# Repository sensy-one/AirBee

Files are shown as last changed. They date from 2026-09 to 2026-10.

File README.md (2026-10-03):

# SENSY-ONE AirBee

Ultra-low-power air quality sensor for **Home Assistant** and **Homey Pro**,
with selectable Zigbee or Bluetooth Low Energy connectivity.

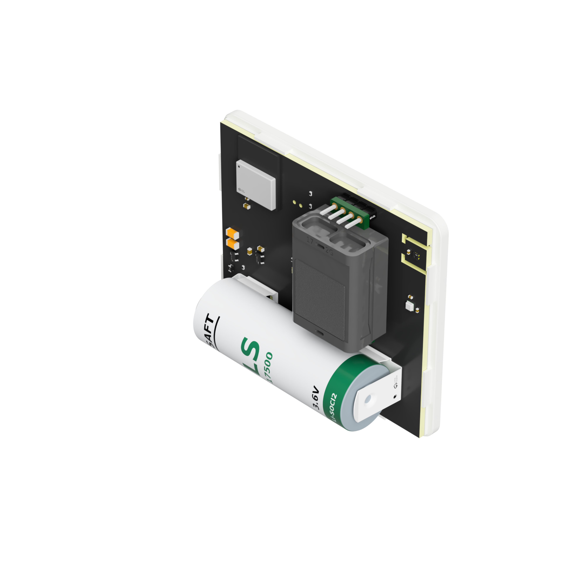
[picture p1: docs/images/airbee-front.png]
Sensy-One AirBee


AirBee measures CO₂, temperature, relative humidity and atmospheric pressure
every five minutes. It uses the pressure reading to compensate the CO₂ sensor
and keeps automatic calibration active while saving power between measurements.

### Smart Home Compatibility

| Platform | Connection | Integration |
|---|---|---|
| Home Assistant | Zigbee | [Zigbee2MQTT](#zigbee2mqtt) or [ZHA](#zha) |
| Home Assistant | Bluetooth LE | [BTHome](#home-assistant-with-bluetooth-le-bthome) |
| Homey Pro | Zigbee or Bluetooth LE | [SENSY-ONE app in the Homey App Store](https://homey.app/en-nl/app/com.sensy-one.airbee/SENSY-ONE/test/) |

All options provide CO₂, temperature, humidity and pressure measurements.
AirBee uses one wireless mode at a time and can join one Zigbee network at a time.

Key features:

- Selectable Zigbee or Bluetooth Low Energy connectivity
- Home Assistant support through Zigbee2MQTT, ZHA or BTHome
- Homey Pro support through the SENSY-ONE app, with Zigbee and Bluetooth LE
- Five-minute CO₂, temperature, humidity and pressure measurements
- Pressure compensation for CO₂ measurements
- Automatic CO₂ baseline calibration
- Manual outdoor-air calibration when needed
- Signed Bluetooth firmware updates without programming hardware

## Getting Started

1. Insert a **SAFT LS17500 3.6 V battery**, following the + and − markings.
   AirBee starts automatically. Leave the button released while inserting the
   battery; holding it during startup starts CO₂ calibration.
2. Check the startup LED: **four red flashes mean Zigbee**, and **four blue
   flashes mean Bluetooth LE**. A new device starts in Zigbee mode.
3. Use the button controls below to select a wireless mode, then follow the
   connection steps for your platform below.

### Button Controls

With AirBee powered on, hold the button until the desired indication, then
release it to confirm. Keep holding past the earlier indications to reach
firmware update or reset.

| Button action | Function | LED indication |
|---|---|---|
| Short press | No action | None |
| Hold for **5 seconds**, then release | Switch between Zigbee and Bluetooth LE | Four red flashes for Zigbee or four blue flashes for Bluetooth LE |
| Hold for **12 seconds**, then release | Start Bluetooth firmware update mode | Green flashes; continuous green blinking after release |
| Hold for **20 seconds**, then release | Clear Zigbee pairing and join a network | Fast red blinking; AirBee restarts in Zigbee mode |
| Hold while inserting the battery | Start [outdoor-air calibration](#co₂-calibration) immediately | Alternating red and blue; solid green on success or solid red on failure |

### Home Assistant with Zigbee

Use either Zigbee2MQTT or ZHA with a compatible Zigbee coordinator. Start pairing
in your chosen integration:

#### Zigbee2MQTT

Open Zigbee2MQTT and enable **Permit join**. To make measurements appear in
Home Assistant, enable Zigbee2MQTT's **Home Assistant discovery** and set up the
[MQTT integration](https://www.home-assistant.io/integrations/mqtt/) in Home
Assistant using the same MQTT broker. See the
[Zigbee2MQTT setup guide](https://www.zigbee2mqtt.io/guide/usage/integrations/home_assistant.html).

#### ZHA

In Home Assistant, open **Settings → Connectivity → Zigbee → Add device**.
If ZHA is not set up yet, follow the
[ZHA setup guide](https://www.home-assistant.io/integrations/zha/).

#### Pair AirBee

1. Enable joining as described above for your integration.
2. Start AirBee in Zigbee mode (**four red flashes**). If it is already powered
   on, remove the battery for at least three seconds and reinsert it with the
   button released.
3. AirBee searches for a network automatically. Wait for the interview to finish,
   then name the device and assign it to a room in Home Assistant.

If AirBee was previously paired, follow [Reset & Re-pair](#reset--re-pair) below.
Allow up to five minutes for measurements to appear.

### Reset & Re-pair

1. Enable pairing on your Zigbee coordinator.
2. With AirBee powered on, hold the button for **20 seconds**. Keep holding
   through the mode flashes and green firmware-update indication.
3. Release when the LED starts **blinking red quickly**.
4. AirBee clears its saved Zigbee network settings, restarts in Zigbee mode and
   automatically searches for a network.

This works from either wireless mode and preserves CO₂ calibration. Removing
the battery or switching modes does not clear the Zigbee pairing.

### Home Assistant with Bluetooth LE (BTHome)

1. Make sure Home Assistant's Bluetooth integration is set up with a working
   Bluetooth adapter or Bluetooth proxy.
2. Select Bluetooth mode (**four blue flashes**) using the button controls above.
3. In Home Assistant, open **Settings → Devices & services** and add the
   discovered **BTHome** device. No Bluetooth pairing or pairing reset is needed.

[BTHome](https://www.home-assistant.io/integrations/bthome/) is built into Home
Assistant; no custom integration is required.

Place AirBee where room air can reach the sensor and allow up to five minutes
for measurements to appear. The LED stays off during normal operation to save
power. A short button press does not trigger a measurement.

### Connect with Homey Pro

1. Open [SENSY-ONE in the Homey App Store](https://homey.app/en-nl/app/com.sensy-one.airbee/SENSY-ONE/test/)
   and select **Install App**. Sign in and choose your Homey Pro.
2. In Homey, go to **Devices, Add device, SENSY-ONE** and choose **AirBee Zigbee**
   or **AirBee BLE**, matching your sensor's wireless mode.

The app is under review by Homey, but you can already install and use it through
the test link above. The App Store warning means the review is still pending.

## Measurements and Accuracy

| Measurement | Sensor | Sensor range | Typical accuracy |
|---|---|---:|---:|
| CO₂ | [Senseair Sunrise](https://senseair.com/product/sunrise/) | 0–10,000 ppm | ±30 ppm + 3% of reading |
| Temperature | [Sensirion SHT45](https://sensirion.com/products/catalog/SHT45) | −40 to 125 °C | ±0.1 °C |
| Relative humidity | [Sensirion SHT45](https://sensirion.com/products/catalog/SHT45) | 0–100 %RH | ±1.0 %RH |
| Pressure | [Bosch BMP581](https://www.bosch-sensortec.com/products/environmental-sensors/pressure-sensors/bmp581/) | 300–1,250 hPa | ±30 Pa absolute at 300–1,100 hPa and −5 to 65 °C; ±6 Pa relative at 700–1,100 hPa and 15 to 55 °C |

Published resolution:

- CO₂: 1 ppm
- Temperature: 0.01 °C
- Relative humidity: 0.01 %RH
- Pressure: 1 hPa

Temperature is transmitted in degrees Celsius. A smart-home frontend can display
the same measurement in Fahrenheit.

## Power and Battery Life

AirBee is designed for the **SAFT LS17500**, a 3.6 V lithium-thionyl-chloride
battery with 3,600 mAh nominal capacity. The estimates below use the average
current measured over **five hours** in each wireless mode, with one measurement
cycle every five minutes.

| Wireless mode | Measured average | No self-discharge | 1% self-discharge per year |
|---|---:|---:|---:|
| Zigbee | **14.74 µA** | **27.88 years** | **≈24.58 years** |
| Bluetooth LE | **12.44 µA** | **33.04 years** | **≈28.53 years** |

The expected battery life is **at least 10 years** with one measurement cycle
every five minutes.

### Performance Test

- [Zigbee - 14.74 µA average over 5 hours](docs/images/airbee-zigbee-power-test-5h.png)
- [Bluetooth LE - 12.44 µA average over 5 hours](docs/images/airbee-ble-power-test-5h.png)

## Wireless Connectivity

### Zigbee

AirBee operates as a sleepy end device and publishes standard Zigbee Cluster
Library measurements:

| Cluster | ID |
|---|---:|
| Basic | `0x0000` |
| Identify | `0x0003` |
| Temperature Measurement | `0x0402` |
| Pressure Measurement | `0x0403` |
| Relative Humidity Measurement | `0x0405` |
| Carbon Dioxide Concentration Measurement | `0x040D` |

- Model: `AirBee`
- Manufacturer: `SENSY-ONE`

No manufacturer-specific measurement payload or custom Zigbee stack is used.

### Bluetooth Low Energy

Bluetooth mode works with Home Assistant through its built-in
[BTHome integration](https://www.home-assistant.io/integrations/bthome/).
No custom integration or pairing is needed.

AirBee sends CO₂, temperature, humidity and pressure using
[BTHome v2](https://bthome.io/). Allow up to five minutes for the next broadcast.

## CO₂ Calibration

AirBee uses automatic CO₂ baseline calibration with a fresh-air reference of
430 ppm. Calibration is retained between measurements, even while the CO₂ sensor
is powered down.

For installation or service, AirBee also provides a protected outdoor-air
calibration:

1. Place AirBee outdoors, away from people, open doors, combustion sources and
   traffic exhaust.
2. Remove the battery for at least three seconds.
3. Hold the button while inserting the battery. Calibration starts immediately;
   release the button when the LED begins alternating red and blue.
4. Leave AirBee undisturbed outdoors while the Sunrise takes repeated
   stabilization measurements and calibrates, which takes approximately ten
   minutes.
5. A solid green LED confirms success; a solid red LED indicates that
   calibration failed. The result remains visible until power is removed.
6. Remove the battery for at least three seconds, then insert it again without
   pressing the button. AirBee starts in its previously selected wireless mode.

Only use this procedure when AirBee is exposed to clean, stable outdoor air. Do
not calibrate indoors, near a person breathing onto the sensor, close to a road,
or near combustion equipment.

## Firmware Updates

Update AirBee wirelessly over Bluetooth Low Energy with Silicon Labs
Simplicity Connect.

1. Download [AirBee-update.gbl](firmware/v1.0.1/AirBee-update.gbl)
   using **Download raw file** on the file page.
2. Install Silicon Labs Simplicity Connect for
   [Android](https://play.google.com/store/apps/details?id=com.siliconlabs.bledemo)
   or [iOS](https://apps.apple.com/us/app/simplicity-connect/id1030932759).
3. Hold the AirBee button for 12 seconds. Continue holding after the first mode
   indication and release the button after the LED flashes green, before
   reaching the 20-second reset indication.
4. Open **Scan** in Simplicity Connect and scan for nearby devices.
5. Connect to **AirBee DFU**.
6. In the connected device view, tap **OTA Firmware** in the upper-right corner
   to open the update menu.
7. Set **Type** to **Partial** and **Mode** to **Reliability**.
8. Select `AirBee-update.gbl` and tap **Upload**.
9. Keep the mobile device close to AirBee until the transfer is complete.

The LED continues to blink green while AirBee is in firmware-update mode.
AirBee verifies the update and restarts automatically within a few seconds,
returning to the previously selected Zigbee or Bluetooth mode. Only firmware
digitally signed by SENSY-ONE is accepted. Never remove the battery while an
update is in progress.

## Hardware

| Function | Component |
|---|---|
| Wireless MCU | Silicon Labs MGM240PA22VNA3 |
| CO₂ | Senseair Sunrise |
| Temperature and humidity | Sensirion SHT45-AD1F-R2 |
| Atmospheric pressure | Bosch BMP581 |
| Battery | SAFT LS17500, 3.6 V, 3,600 mAh Li-SOCl₂ |

The [BTHome license statement](docs/license-statement-bthome.pdf) is included in this repository.

## Let's Connect

- Questions or need help? Join our [Discord community](https://discord.gg/TB78Wprn66).
- Found a bug or have an idea? Open an [issue on GitHub](https://github.com/sensy-one/AirBee/issues).

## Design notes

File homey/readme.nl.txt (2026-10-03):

AirBee geeft je inzicht in de luchtkwaliteit en het klimaat in huis. De compacte, draadloze sensor meet CO₂, temperatuur, luchtvochtigheid en luchtdruk. Zo zie je wanneer het tijd is om te ventileren en houd je de omstandigheden in je slaapkamer, woonkamer of werkkamer in de gaten.

Verbind AirBee met Homey Pro via Zigbee of Bluetooth LE. Je ontvangt elke vijf minuten nieuwe metingen.

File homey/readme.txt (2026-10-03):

AirBee helps you understand the air quality and climate in your home. This compact, wireless sensor measures CO₂, temperature, humidity and air pressure, so you can see when it is time to ventilate and keep track of conditions in your bedroom, living room or home office.

Connect AirBee to Homey Pro over Zigbee or Bluetooth LE and receive new measurements every five minutes.

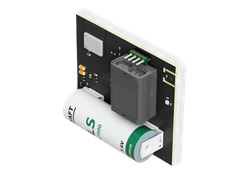
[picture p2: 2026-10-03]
homey/assets/images/airbee-front-small.png

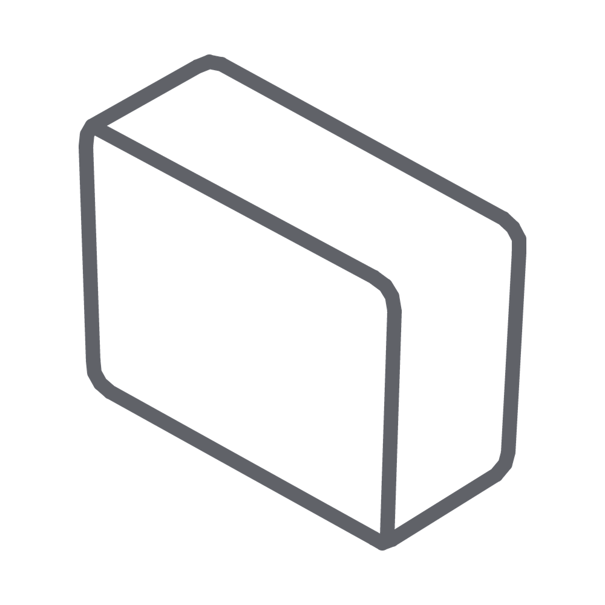
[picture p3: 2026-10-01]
homey/drivers/airbee-zigbee/assets/images/xlarge.png

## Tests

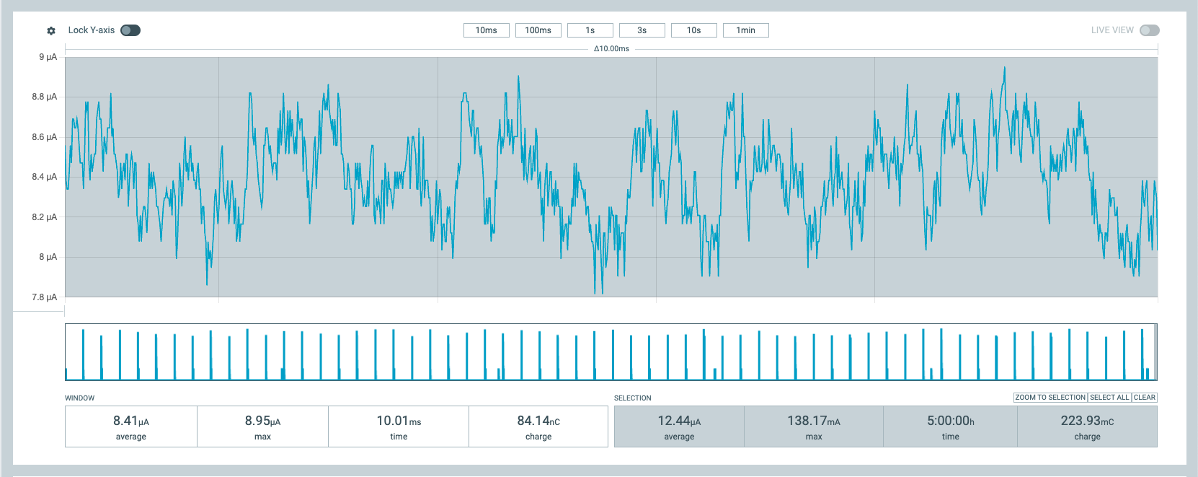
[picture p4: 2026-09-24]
docs/images/airbee-ble-power-test-5h.png

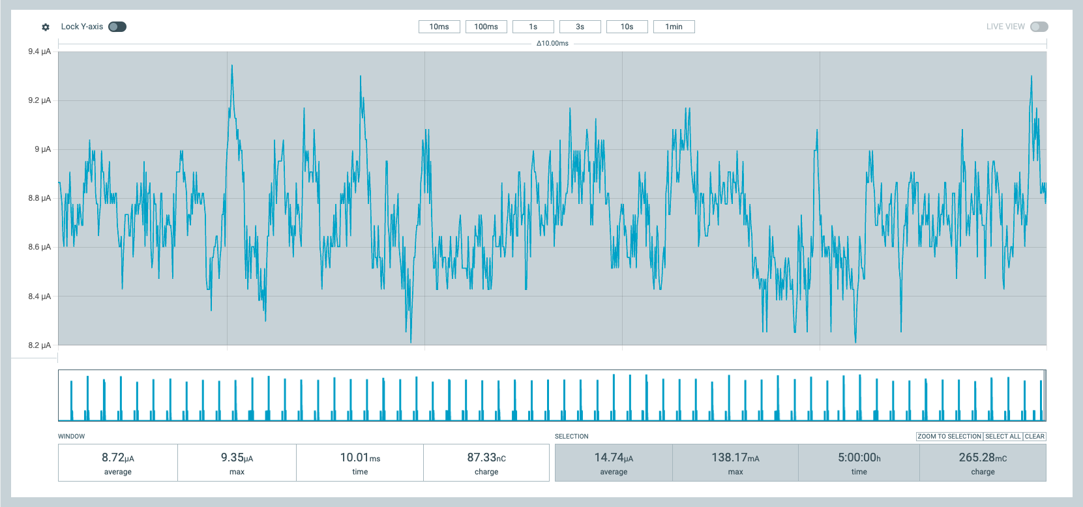
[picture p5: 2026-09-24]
docs/images/airbee-zigbee-power-test-5h.png

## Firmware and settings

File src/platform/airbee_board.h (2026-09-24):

#pragma once

#include "em_device.h"
#include "em_gpio.h"
#include "sl_gpio.h"

#define AIRBEE_I2C_PERIPHERAL I2C0
#define AIRBEE_I2C_SDA_PORT   SL_GPIO_PORT_B
#define AIRBEE_I2C_SDA_PIN    4U
#define AIRBEE_I2C_SCL_PORT   SL_GPIO_PORT_B
#define AIRBEE_I2C_SCL_PIN    3U

#define AIRBEE_SUN_SWITCH_PORT gpioPortD
#define AIRBEE_SUN_SWITCH_PIN  0U
#define AIRBEE_SUN_ENABLE_PORT gpioPortC
#define AIRBEE_SUN_ENABLE_PIN  2U
#define AIRBEE_SUN_NRDY_PORT   gpioPortC
#define AIRBEE_SUN_NRDY_PIN    1U

#define AIRBEE_LED_RED_PORT         gpioPortA
#define AIRBEE_LED_RED_PIN          7U
#define AIRBEE_LED_GREEN_PORT       gpioPortA
#define AIRBEE_LED_GREEN_PIN        8U
#define AIRBEE_LED_BLUE_PORT        gpioPortD
#define AIRBEE_LED_BLUE_PIN         3U
#define AIRBEE_BUTTON_PORT          gpioPortD
#define AIRBEE_BUTTON_PIN           2U
#define AIRBEE_SUN_BUS_CONNECTED    1U
#define AIRBEE_SUN_BUS_DISCONNECTED 0U
#define AIRBEE_SUN_ENABLED          1U
#define AIRBEE_SUN_DISABLED         0U
#define AIRBEE_LED_OFF              1U

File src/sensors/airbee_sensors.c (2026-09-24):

#include "airbee_sensors.h"

#include <stddef.h>
#include <string.h>

#include "airbee_board.h"
#include "em_gpio.h"
#include "gpiointerrupt.h"
#include "nvm3.h"
#include "nvm3_default.h"
#include "sl_i2cspm.h"
#include "sl_sleeptimer.h"

#define SHT45_ADDRESS                   0x44U
#define SHT45_MEASURE_LOW_REPEATABILITY 0xE0U
#define SHT45_CONVERSION_DELAY_MS       5U
#define SHT45_MAX_READ_ATTEMPTS         3U

#define BMP581_ADDRESS            0x46U
#define BMP581_REG_CHIP_ID        0x01U
#define BMP581_REG_INT_SOURCE     0x15U
#define BMP581_REG_TEMP_DATA_XLSB 0x1DU
#define BMP581_REG_INT_STATUS     0x27U
#define BMP581_REG_OSR_CONFIG     0x36U
#define BMP581_REG_ODR_CONFIG     0x37U
#define BMP581_DRDY_BIT           0x01U
#define BMP581_CHIP_ID_A          0x50U
#define BMP581_CHIP_ID_B          0x51U
#define BMP581_PRESS_ENABLE       0x40U
#define BMP581_ODR_1_HZ           0x1CU
#define BMP581_ODR_MASK           0x7CU
#define BMP581_ODR_POSITION       2U
#define BMP581_DEEP_DISABLE       0x80U
#define BMP581_POWER_MODE_MASK    0x03U
#define BMP581_POWER_MODE_STANDBY 0x00U
#define BMP581_POWER_MODE_FORCED  0x02U
#define BMP581_POLL_DELAY_MS      5U
#define BMP581_MAX_POLLS          40U

#define SUNRISE_ADDRESS                        0x68U
#define SUNRISE_REG_ERROR_STATUS               0x00U
#define SUNRISE_REG_CALIBRATION_STATUS         0x80U
#define SUNRISE_REG_CALIBRATION_COMMAND        0x82U
#define SUNRISE_REG_MEASUREMENT_MODE           0x95U
#define SUNRISE_REG_ABC_TARGET                 0x9EU
#define SUNRISE_REG_SCR                        0xA3U
#define SUNRISE_REG_METER_CONTROL              0xA5U
#define SUNRISE_REG_SENSOR_STATE               0xC2U
#define SUNRISE_REG_START_MEASUREMENT          0xC3U
#define SUNRISE_REG_PRESSURE                   0xDCU
#define SUNRISE_MODE_SINGLE                    0x01U
#define SUNRISE_START_SINGLE                   0x01U
#define SUNRISE_SCR_RESET                      0xFFU
#define SUNRISE_CALIBRATION_BACKGROUND         0x7C06U
#define SUNRISE_CALIBRATION_BACKGROUND_BIT     0x0020U
#define SUNRISE_ABC_TARGET_PPM                 430U
#define SUNRISE_ABC_DISABLED_BIT               0x02U
#define SUNRISE_PRESSURE_COMP_DISABLED_BIT     0x10U
#define SUNRISE_STARTUP_DELAY_MS               35U
#define SUNRISE_EEPROM_DELAY_MS                120U
#define SUNRISE_RESET_DELAY_MS                 100U
#define SUNRISE_MIN_READY_DELAY_MS             100U
#define SUNRISE_SAMPLE_TIMEOUT_MS              300U
#define SUNRISE_DESIRED_SAMPLES                4U
#define SUNRISE_STATE_WORD_COUNT               15U
#define SUNRISE_STATE_ABC_TIME_INDEX           1U
#define SUNRISE_STATE_PRESSURE_INDEX           13U
#define SUNRISE_READY_MARGIN_MS                800U
#define SUNRISE_CALIBRATION_SAMPLE_INTERVAL_MS 30000UL
#define SUNRISE_CALIBRATION_SAMPLE_COUNT       20U
#define SUNRISE_STATE_NVM_KEY                  0x0000A1BFUL
#define SUNRISE_STATE_NVM_MAGIC                0x41425331UL
#define SUNRISE_STATE_NVM_VERSION              1U
#define SUNRISE_STATE_SAVE_INTERVAL_MS         86400000UL

typedef enum {
  SENSOR_STATE_IDLE,
  SENSOR_STATE_WAIT_ENVIRONMENT,
  SENSOR_STATE_SUNRISE_STARTUP,
  SENSOR_STATE_SUNRISE_CHECK_CONFIG,
  SENSOR_STATE_SUNRISE_EEPROM_WAIT,
  SENSOR_STATE_SUNRISE_RESET_WAIT,
  SENSOR_STATE_SUNRISE_WAIT_MINIMUM,
  SENSOR_STATE_SUNRISE_WAIT_READY,
} sensor_state_t;

typedef enum {
  CALIBRATION_STATE_IDLE,
  CALIBRATION_STATE_STARTUP,
  CALIBRATION_STATE_SAMPLE_START,
  CALIBRATION_STATE_SAMPLE_WAIT_MINIMUM,
  CALIBRATION_STATE_SAMPLE_WAIT_READY,
  CALIBRATION_STATE_COMMAND,
  CALIBRATION_STATE_FINAL_WAIT_MINIMUM,
  CALIBRATION_STATE_FINAL_WAIT_READY,
} calibration_state_t;

typedef struct {
  uint32_t magic;
  uint16_t version;
  uint16_t off_time_remainder_seconds;
  uint16_t state[SUNRISE_STATE_WORD_COUNT];
} sunrise_nvm_state_t;

static sensor_state_t state = SENSOR_STATE_IDLE;
static calibration_state_t calibration_state = CALIBRATION_STATE_IDLE;
static airbee_measurements_t measurements;
static bool bmp581_available;
static bool sht45_pending;
static uint8_t sht45_read_attempts;
static bool bmp581_pending;
static uint8_t bmp581_poll_count;
static bool sunrise_config_known;
static bool sunrise_state_valid;
static bool sunrise_state_loaded;
static bool sunrise_is_powered;
static bool sunrise_power_down_tracking;
static uint64_t sunrise_powered_down_tick;
static uint32_t sunrise_off_time_remainder_ms;
static uint32_t sunrise_state_save_elapsed_ms;
static uint8_t calibration_sample_count;
static uint16_t sunrise_state[SUNRISE_STATE_WORD_COUNT];
static airbee_sunrise_ready_isr_callback_t sunrise_ready_callback;

static I2CSPM_Init_TypeDef i2c_init = {
  .port = AIRBEE_I2C_PERIPHERAL,
  .sclPort = AIRBEE_I2C_SCL_PORT,
  .sclPin = AIRBEE_I2C_SCL_PIN,
  .sdaPort = AIRBEE_I2C_SDA_PORT,
  .sdaPin = AIRBEE_I2C_SDA_PIN,
  .i2cRefFreq = 0U,
  .i2cMaxFreq = I2C_FREQ_STANDARD_MAX,
  .i2cClhr = i2cClockHLRStandard,
};

static bool i2c_transfer(uint8_t address,
                         uint16_t flags,
                         uint8_t *write_data,
                         uint16_t write_length,
                         uint8_t *read_data,
                         uint16_t read_length)
{
  I2C_TransferSeq_TypeDef sequence = { 0 };
  sequence.addr = (uint16_t)address << 1;
  sequence.flags = flags;
  if (flags == I2C_FLAG_READ) {
    sequence.buf[0].data = read_data;
    sequence.buf[0].len = read_length;
  } else {
    sequence.buf[0].data = write_data;
    sequence.buf[0].len = write_length;
    sequence.buf[1].data = read_data;
    sequence.buf[1].len = read_length;
  }
  return I2CSPM_Transfer(AIRBEE_I2C_PERIPHERAL, &sequence) == i2cTransferDone;
}

static bool i2c_probe(uint8_t address)
{
  return i2c_transfer(address, I2C_FLAG_WRITE, NULL, 0U, NULL, 0U);
}

static bool i2c_write(uint8_t address, const uint8_t *data, uint8_t length)
{
  return i2c_transfer(
    address, I2C_FLAG_WRITE, (uint8_t *)data, length, NULL, 0U);
}

static bool i2c_read(uint8_t address, uint8_t *data, uint8_t length)
{
  return i2c_transfer(address, I2C_FLAG_READ, NULL, 0U, data, length);
}

static bool
i2c_read_register(uint8_t address, uint8_t reg, uint8_t *data, uint8_t length)
{
  return i2c_transfer(address, I2C_FLAG_WRITE_READ, &reg, 1U, data, length);
}

static bool i2c_write_register(uint8_t address,
                               uint8_t reg,
                               const uint8_t *data,
                               uint8_t length)
{
  uint8_t buffer[32];
  if (length > (sizeof(buffer) - 1U)) {
    return false;
  }

  buffer[0] = reg;
  if (length > 0U) {
    memcpy(&buffer[1], data, length);
  }
  return i2c_write(address, buffer, (uint8_t)(length + 1U));
}

static bool i2c_write_register8(uint8_t address, uint8_t reg, uint8_t value)
{
  return i2c_write_register(address, reg, &value, 1U);
}

static uint16_t read_u16_be(const uint8_t *data)
{
  return ((uint16_t)data[0] << 8) | data[1];
}
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
